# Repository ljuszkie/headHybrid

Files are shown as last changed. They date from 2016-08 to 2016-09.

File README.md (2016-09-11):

# headHybrid 
Simple hybrid headphone amplifier. Project was created in
KiCad BZR 5054 on Linux, verified to be editable in KiCad 4.0.2, which
is target version (switch to new version soon). Board view image and
pdf schematic can be found in preview folder.

Prosty hybrydowy wzmacniacz słuchawkowy. Projekt utworzony w KiCadzie
BZR 5054 na Linuksie, można go edytować w KiCadzie 4.0.2, który jest
docelową wersją (przejście na nową wersję wkrótce). Obrazek
z widokiem płytki i schemat w formacie pdf znajdują się w folderze
preview.

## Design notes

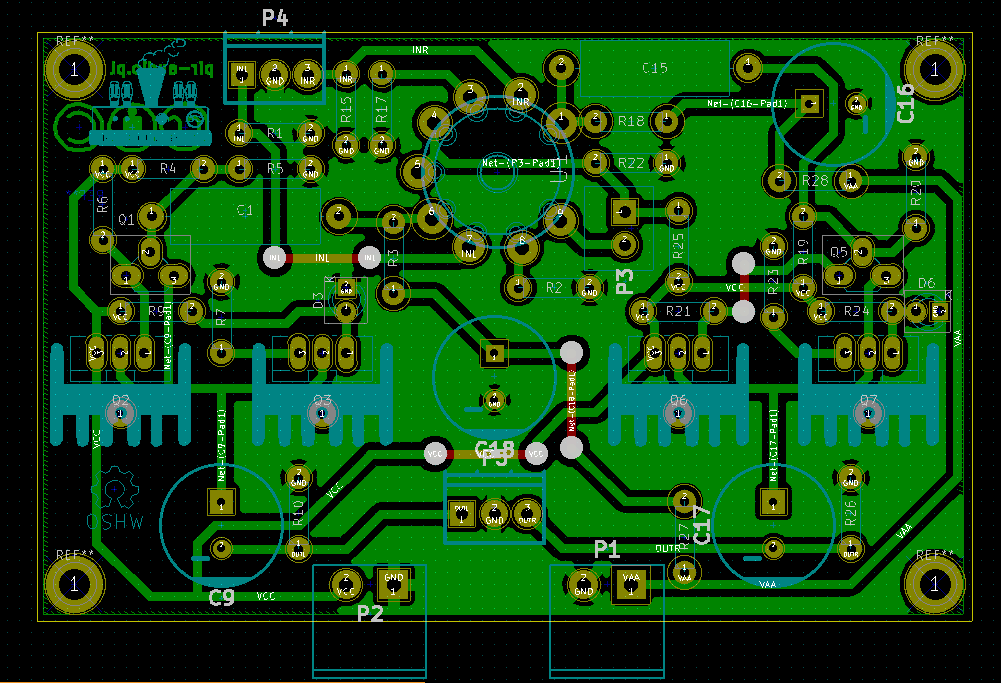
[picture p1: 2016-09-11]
preview/board.png

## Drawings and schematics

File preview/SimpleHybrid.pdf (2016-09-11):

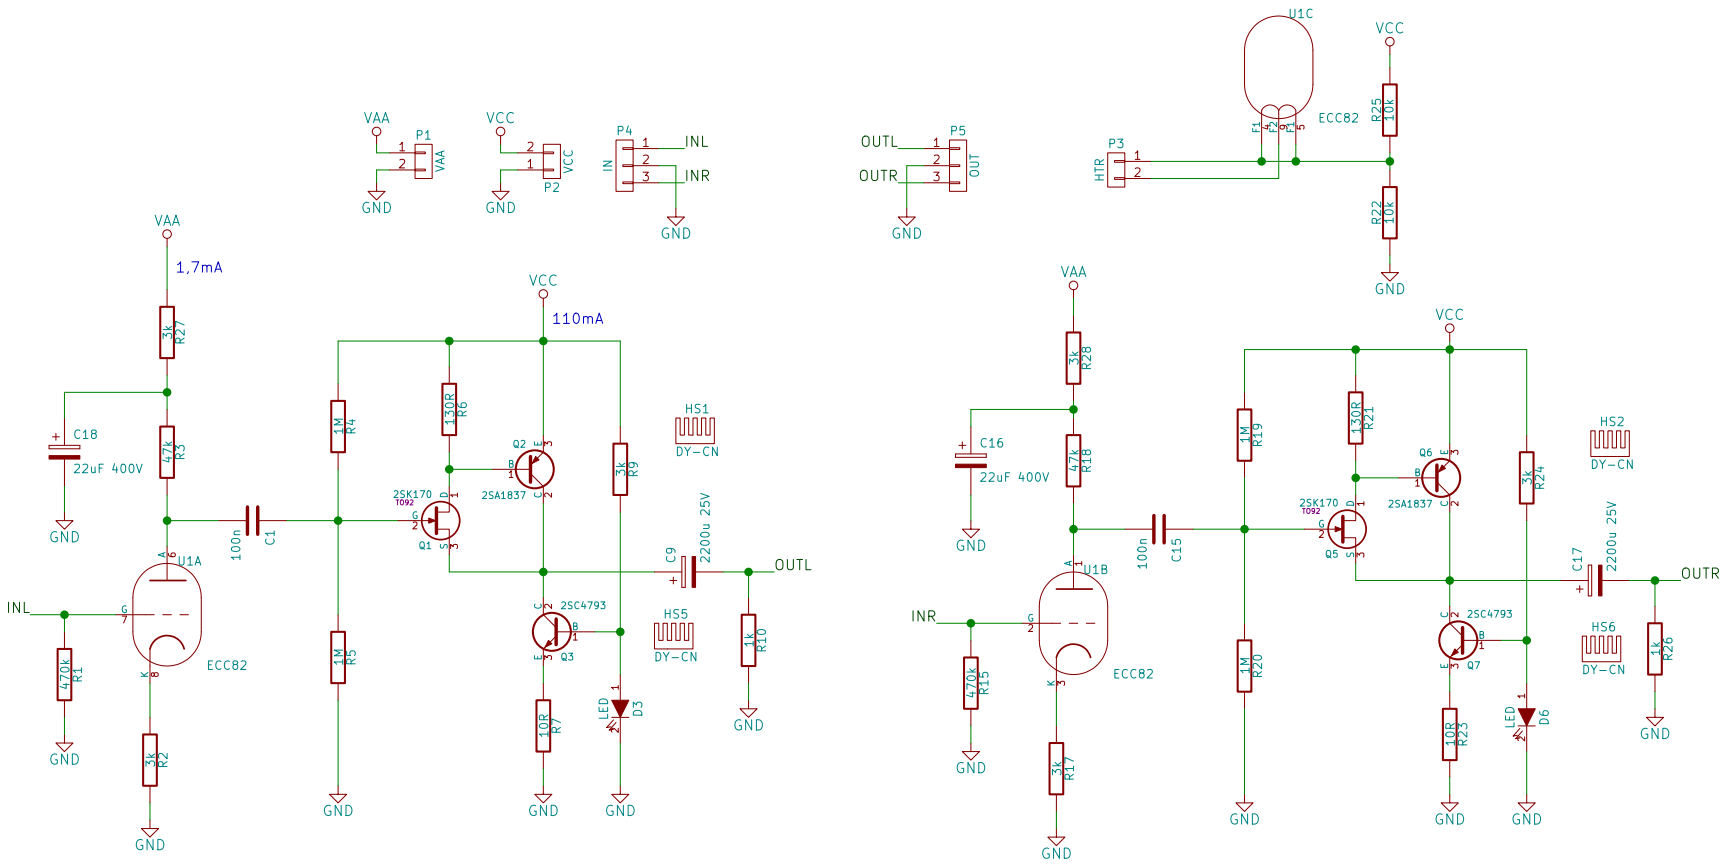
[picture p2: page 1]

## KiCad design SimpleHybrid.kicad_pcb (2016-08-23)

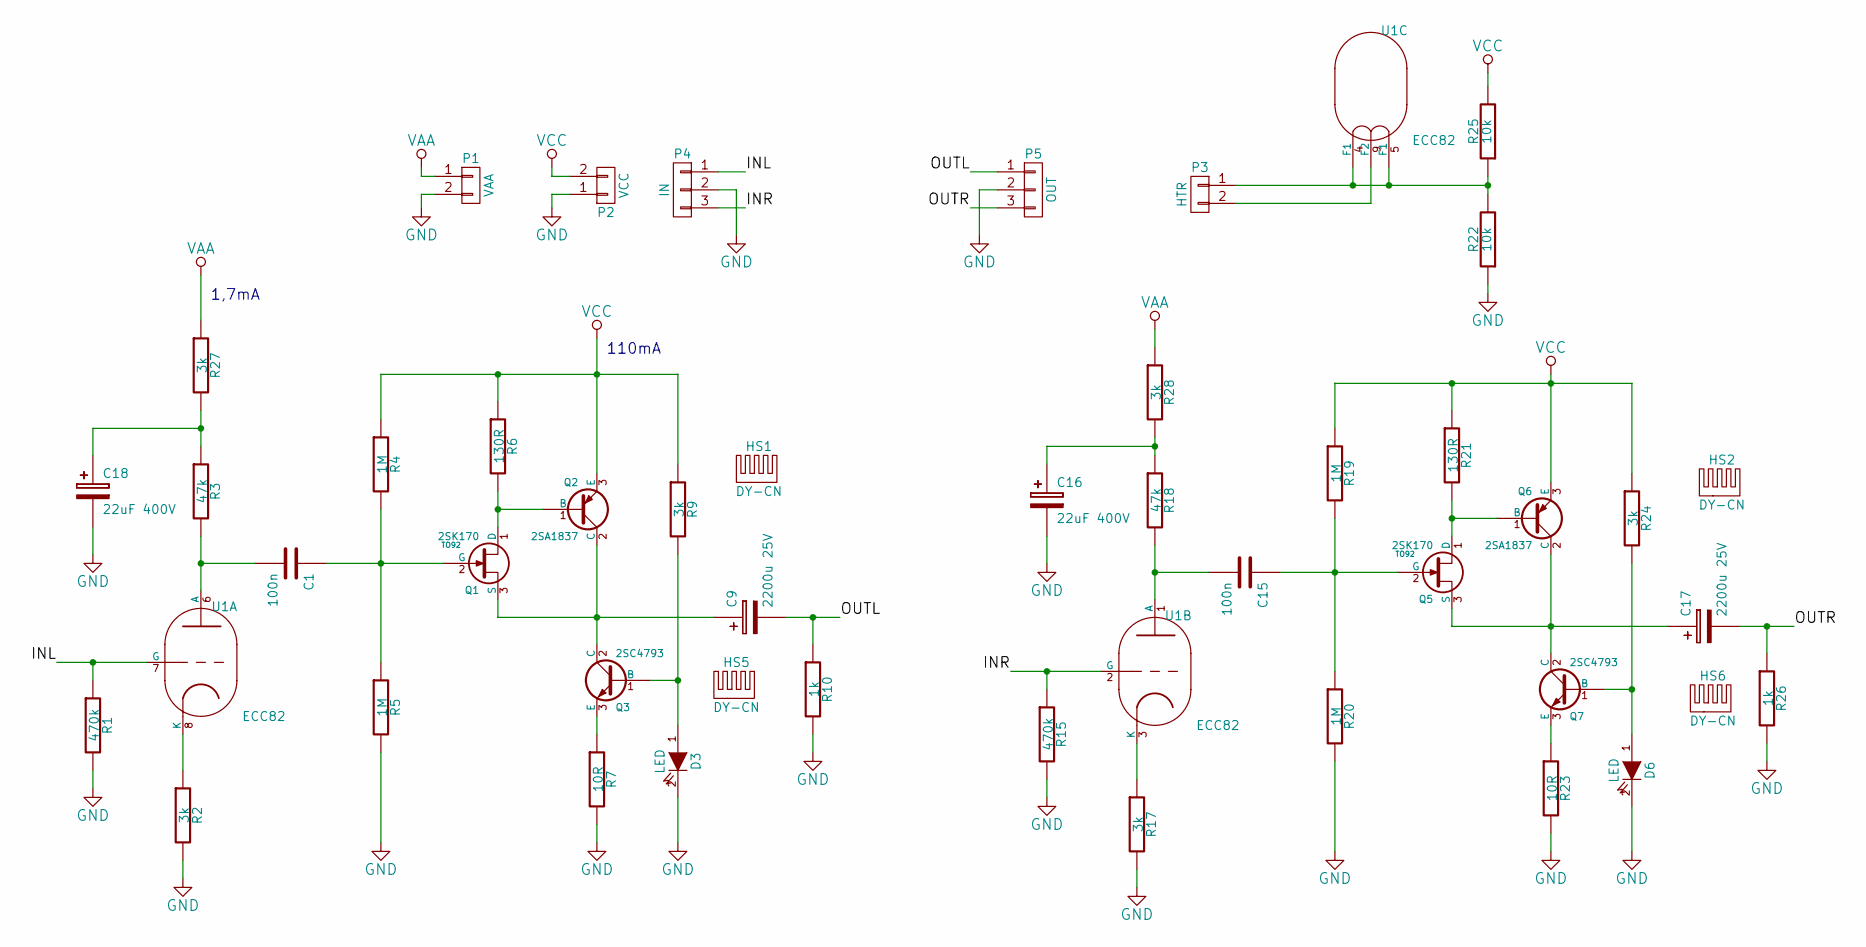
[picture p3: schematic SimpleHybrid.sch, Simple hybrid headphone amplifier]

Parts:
C1, C15: 100n
C9, C17: 2200u 25V
C16, C18: 22uF 400V
D3, D6: LED
HS1, HS2, HS5, HS6: DY-CN
P1: VAA
P2: VCC
P3: HTR
P4: IN
P5: OUT
Q1, Q5: 2SK170; TO92
Q2, Q6: 2SA1837
Q3, Q7: 2SC4793
R1, R15: 470k
R2, R9, R17, R24, R27, R28: 3k
R3, R18: 47k
R4, R5, R19, R20: 1M
R6, R21: 130R
R7, R23: 10R
R10, R26: 1k
R22, R25: 10k
U1: ECC82; VALVE-NOVAL_P

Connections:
/INL: P4.1, R1.1, U1.7 (G)
/INR: P4.3, R15.1, U1.2 (G)
/OUTL: C9.2, P5.1, R10.1
/OUTR: C17.2, P5.3, R26.1
GND: C16.2, C18.2, D3.2 (K), D6.2 (K), P1.2, P2.1, P4.2, P5.2, R1.2, R2.2, R5.2, R7.2, R10.2, R15.2, R17.2, R20.2, R22.1, R23.2, R26.2
unnamed: C1.1, Q1.2 (G), R4.2, R5.1
unnamed: C1.2, R3.2, U1.6 (A)
unnamed: C9.1, Q1.3 (S), Q2.2 (C), Q3.2 (C)
unnamed: C15.1, Q5.2 (G), R19.2, R20.1
unnamed: C15.2, R18.2, U1.1 (A)
unnamed: C16.1, R18.1, R28.2
unnamed: C17.1, Q5.3 (S), Q6.2 (C), Q7.2 (C)
unnamed: C18.1, R3.1, R27.2
unnamed: D3.1 (A), Q3.1 (B), R9.2
unnamed: D6.1 (A), Q7.1 (B), R24.2
unnamed: P3.1, R22.2, R25.1, U1.4 (F1), U1.5 (F1)
unnamed: P3.2, U1.9 (F2)
unnamed: Q1.1 (D), Q2.1 (B), R6.2
unnamed: Q3.3 (E), R7.1
unnamed: Q5.1 (D), Q6.1 (B), R21.2
unnamed: Q7.3 (E), R23.1
unnamed: R2.1, U1.8 (K)
unnamed: R17.1, U1.3 (K)
VAA: P1.1, R27.1, R28.1
VCC: P2.2, Q2.3 (E), Q6.3 (E), R4.1, R6.1, R9.1, R19.1, R21.1, R24.1, R25.2

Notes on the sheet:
1,7mA
110mA

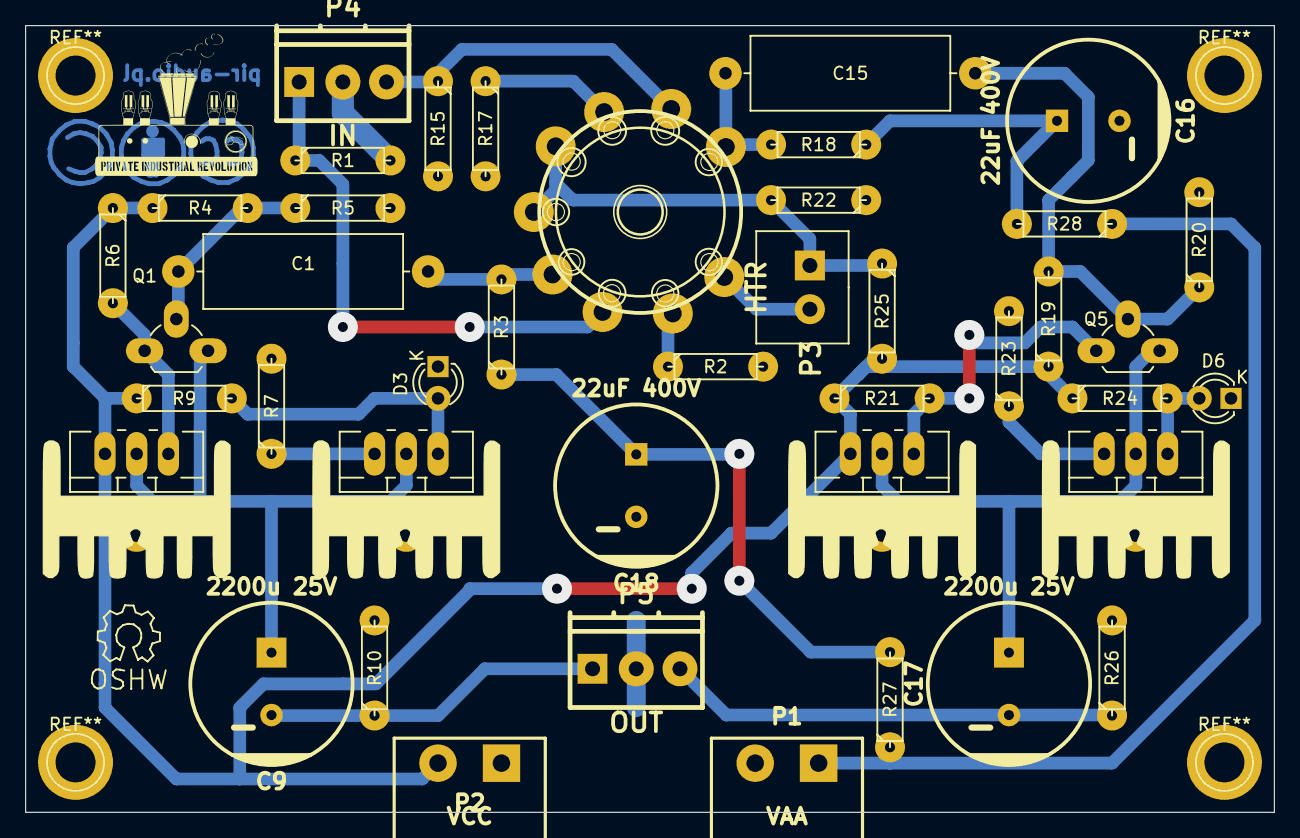
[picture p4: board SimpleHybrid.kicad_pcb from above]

Board: 2 copper layers, 100.0 x 63.0 mm, 46 parts (0 on the bottom side), 25 nets.

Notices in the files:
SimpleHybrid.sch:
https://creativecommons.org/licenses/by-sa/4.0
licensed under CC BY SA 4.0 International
